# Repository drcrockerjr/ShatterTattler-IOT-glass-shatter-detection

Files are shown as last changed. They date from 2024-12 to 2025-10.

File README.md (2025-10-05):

# ShatterTattler

ShatterTattler is an embedded audio signal analysis platform designed to run deep learning sound event classification in a more decentralized manner. The system is specifically built for low power, glass shatter event detection in residential or commercial environments. Due to the flexible deep learning approach the system can be trained and optimized for real time acoustic sensing applications such as environmental monitoring, industrial condition assessment, and anomaly detection.

# Overview

ShatterTattler integrates high-fidelity audio capture with efficient preprocessing and inference. It leverages the ESP32-S3 microcontroller for connectivity and control, with a PCM1841-Q1 quad channel ADC for microphone audio input from multiple sources. Audio Telemetry data is then transported vio BLE 5.0 from the edge ESP32 to an Nvidia Jetson Orin Nano where the bulk of the heavy processing occurs. Upon data arrival, preprocessing (filtering, spectral analysis, feature extraction) is performed on the Jetson upon data arrival device CPU before LSTM model inference occurs on the device GPU. A general overview is described in this image: 


# Hardware Components
## ESP32-S3

- Integrated Wi-Fi + Bluetooth LE 5.0
- Up to 512KB SRAM and external PSRAM support
- PCM1841-Q1 (TI Burr-Brown™ Audio ADC) Quad-channel, 32-bit, up to 192kHz sampling
- 123dB dynamic range (with DRE enabled)
- Interfaces: TDM, I²S, or Left-Justified formats
- Integrated MICBIAS (2.75V, 20mA drive) for powering microphones
- Built-in PLL, DC-removal HPF, and configurable digital filters
- Low power consumption (~18–25mW/channel at 48kHz)

## Software Stack

- Arduino Framework (ESP-IDF optional): for ESP32-S3 development
- BLE GATT Server: for wireless configuration and streaming metadata
- DSP Preprocessing: band-pass, low-pass, amplification
- ML Inference: models trained in PyTorch/TensorFlow Jetson runs model directly

# Key Features

- Multi channel audio capture and preprocessing at the edge
- Jeston device neural network inference (CNN, LSTM, or Transformer-lite models)
- BLE-based telemetry and configuration
- Modular design for integration into larger IoT sensing systems

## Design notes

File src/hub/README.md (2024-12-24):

Place holder for Jetson hub run instructions

#Preprocessing
For ffmped:
ffmpeg -i ../../data/VOICEe_clean/audio/synthetic_204.wav -c:a pcm_s16le ../../data/VOICEe_clean/audio/synthetic_204_s16le.wav

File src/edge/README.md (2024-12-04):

Place holder for edge device run instructions

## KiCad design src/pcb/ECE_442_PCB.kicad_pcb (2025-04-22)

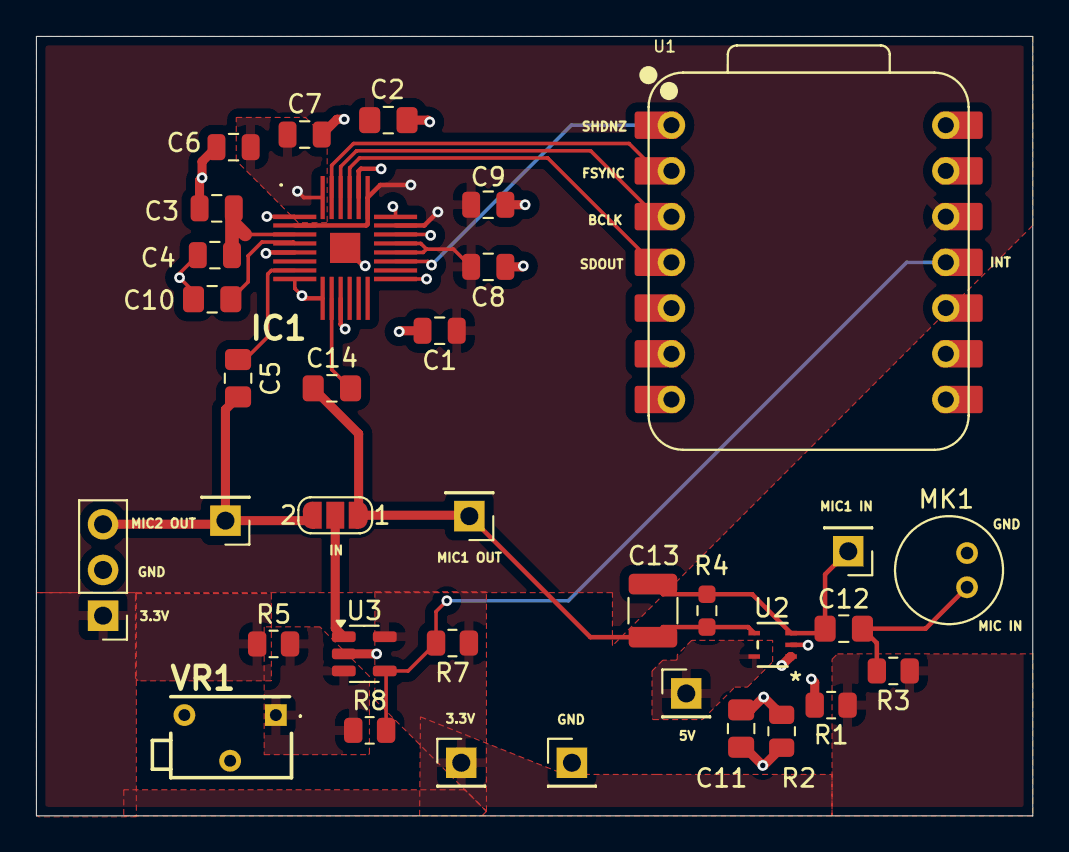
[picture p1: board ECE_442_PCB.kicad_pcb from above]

Board: 2 copper layers, 55.4 x 43.3 mm, 35 parts (0 on the bottom side), 20 nets.

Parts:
C1, C3, C6, C9: 0.1uF; C_0805_2012Metric
C2, C5, C10, C14: 1uF; C_0805_2012Metric_Pad1.18x1.45mm_HandSolder
C4, C7, C8: 10uF; C_0805_2012Metric
C11: 3.3u; C_0805_2012Metric_Pad1.18x1.45mm_HandSolder
C12: 4.7u; C_0805_2012Metric_Pad1.18x1.45mm_HandSolder
C13: 17.6u; C_1210_3225Metric
IC1: PCM1841QRGERQ1
J1, J2, J3, J4, J5, J7: Conn_01x01_Pin; PinHeader_1x01_P2.54mm_Vertical
J6: Conn_01x03_Pin; PinHeader_1x03_P2.54mm_Vertical
JP2: SolderJumper_3_Open; SolderJumper-3_P1.3mm_Open_RoundedPad1.0x1.5mm_NumberLabels
MK1: Microphone; CUI_CMC-5042PF-AC
R1, R2, R5, R8: 100K; R_0805_2012Metric
R3: 5.9K; R_0805_2012Metric
R4: 67.8K; R_0603_1608Metric_Pad0.98x0.95mm_HandSolder
R7: 10K; R_0805_2012Metric
U1: MOUDLE-SEEEDUINO-XIAO-ESP32S3; XIAO-ESP32S3-DIP
U2: TLV6741DCKR; DCK5_TEX-L
U3: TL331KDBVR; SOT-23-5
VR1: 3266X-1-104LF; 3266X1104LF

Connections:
+3.3V: C1.2, C2.2, C8.2, C9.2, IC1.1 (AVDD), IC1.15 (FMT1), IC1.16 (FMT0), IC1.18 (MD0), IC1.19 (IOVDD), J3.1, J6.1, R1.1, R3.1, R5.1, R7.1, U1.12 (3V3), U3.5 (V+)
+5V: J5.1, U2.5 (V+)
/AREG: C3.1, C4.1, IC1.2 (AREG)
/DREG: C6.1, C7.2, IC1.24 (DREG)
/IN+: C11.2, R1.2, R2.1, U2.1 (+IN)
/MIC: C12.1, MK1.MIC, R3.2
BCLK: IC1.22 (BCLK), U1.3 (PA10_A2_D2)
FSYNC: IC1.23 (FSYNC), U1.2 (PA4_A1_D1)
GND: C1.1, C2.1, C3.2, C4.2, C6.2, C7.1, C8.1, C9.1, C10.1, C11.1, IC1.4 (AVSS_1), IC1.7 (IN1M), IC1.9 (IN2M), IC1.17 (MSZ), IC1.20 (MD1), IC1.25 (GND), IC1.A1 (AVSS_2), IC1.A2 (AVSS_3), IC1.A3 (AVSS_4), IC1.A4 (AVSS_5), J4.1, J6.2, MK1.GND, R2.2, U1.13 (GND), U2.2 (V), U3.2 (V-), VR1.2 (WIPER)
IN: JP2.2 (C), U3.1 (-)
INT: R7.2, R8.2, U1.11 (PA6_A10_D10_MOSI), U3.4
MIC1_OUT: C13.1, C14.1, J1.1, JP2.1 (A), R4.2, U2.4 (OUT)
MIC2_OUT: C5.1, J6.3, J7.1, JP2.3 (B)
MIC_IN: C12.2, C13.2, J2.1, R4.1, U2.3 (IN)
unnamed: C5.2, IC1.6 (IN1P)
unnamed: C14.2, IC1.8 (IN2P)
unnamed: C10.2, IC1.3 (VREF)
SDOUT: IC1.21 (SDOUT), U1.4 (PA11_A3_D3)
SHDNZ: IC1.14 (SHDNZ), U1.1 (PA02_A0_D0)
VA: R5.2, R8.1, U3.3 (+), VR1.1 (CCW)

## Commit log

2025-01-22 bluetooth works with esp32, able to connect and recv data
2025-01-24 big changes to test ble with jetson device and saving arrays to dataset for each edge node
2025-03-25 deleted pcb files
    [ECE_442_PCB.kicad_pcb, ECE_442_PCB.kicad_sch]
2025-03-25 updated pcb files
    [ECE_442_PCB.kicad_pcb, ECE_442_PCB.kicad_sch]
